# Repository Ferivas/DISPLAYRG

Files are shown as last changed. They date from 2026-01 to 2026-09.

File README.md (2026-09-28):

# Display SAC-A (DISPLAYRG)

Controlador de display LED RG de 8×32 píxeles basado en **ATmega328** (también compatible con ATmega328P), cristal externo de **7.3728 MHz**.

## Estructura del repositorio

| Directorio | Contenido |
|---|---|
| `BASCOM/` | Firmware original en BASCOM-AVR (`DISPLAYSACA_main.bas` + `DISPLAYSACA_archivos.bas`, bootloader XMODEM). Referencia del protocolo y del barrido. |
| `SCH/` | Proyecto Altium Designer (esquemáticos, PCB, salidas generadas). |
| `display/` | Firmware actual en C (PlatformIO + avr-gcc). Maneja el display, serie y LED indicador. |
| `bootloader/` | Bootloader Optiboot para ATmega328 (PlatformIO/Makefile, grabación por USBASP). |

## Firmware `display/`

Puerto a C del firmware BASCOM. Matriz RG multiplexada por registros de desplazamiento de 16 bits (datos `PB0`, reloj `PB1`, todos comparten bus):

- **Columnas** (16 posiciones, cada una cubre 2 columnas físicas 0–15 y 16–31): latch `PD2`, habilitación `PD3`
- **Filas mitad izquierda** (byte rojo + byte verde): latch `PD6`, habilitación `PD7`
- **Filas mitad derecha**: latch `PD4`, habilitación `PD5`
- **LED de señalización**: `PC2` en alto, 100 ms encendido / 900 ms apagado (Timer0 a 100 Hz)

### Temporización

- **Timer2**: barrido de columnas a ~3840 Hz (`TCNT2=226`, prescaler 64) → frame completo de 16 columnas a **240 Hz** (el original BASCOM iba a 960 Hz / 60 Hz y parpadeaba).
- **Timer0**: tick a 100 Hz (`TCNT0=184`, prescaler 1024) para el LED PC2 y el avance de scroll/texto (cada 100 ms).

### Protocolo serie (9600 baud, 8N1)

Trama: **`$` + mensaje + ENTER (`\r`)**. Todo byte fuera de una trama `$`…ENTER se descarta (resincroniza tras ruido). Comandos:

| Comando | Ejemplo | Descripción |
|---|---|---|
| `SETTXT,<texto>,<color>` | `$SETTXT,HOLA,2` | Texto (máx. 48 cars.), color 1=rojo, 2=verde, 3=amarillo |
| `SETCOL,<color>` | `$SETCOL,3` | Cambia color del texto actual |
| `SETSCR,<0\|1>` | `$SETSCR,1` | Scroll on/off (1 columna / 100 ms) |
| `SETTST,<0-4>` | `$SETTST,1` | 0=normal, 1=todo rojo, 2=todo verde, 3=barrido de columna, 4=mitad izq. roja / der. verde |

Respuestas: `OK` o `ERR n`. Comandos sin `$` se ignoran.

### Fuente 5×7

64 caracteres en flash: `0-9`, `A-Z`, **`a-z`**, espacio y punto. Glifo `E` corregido (la última columna era `0x07` en vez de `0x49`).

### Persistencia (EEPROM)

Texto, color y scroll se guardan en EEPROM (magic `0xA5` en addr 0, color en 1, scroll en 2, texto en 3–50) cada vez que llega `SETTXT`/`SETCOL`/`SETSCR`, usando `eeprom_update_*` (solo escribe bytes cambiados). Al arrancar se restauran; si la EEPROM está virgen se usan los valores de inicio ("Bienvenidos a su gimnasio", verde, scroll 1) y se guardan.

### Orientación

El panel está cableado invertido en ambos ejes, así que `display_render()` rota el texto 180°: voltea las filas del glifo (bit r ↔ 6-r) y escribe la columna `31 - pos`. Los modos `SETTST` 3 (barrido) y 4 (mitades) están compensados para mantener su sentido físico.

### Compilar y grabar por USBASP

```bash
cd display
make              # compila entorno atmega328
make upload       # graba ATmega328 por USBASP
make upload328p   # graba ATmega328P por USBASP
pio device monitor   # monitor serie a 9600 baud (recordar el $ delante)
```

Comandos `avrdude` equivalentes (esta tarjeta 328 necesita SCK lento `-B 100`):

```bash
# Comprobar conexión y firma (ATmega328 = 1E 95 14; la P es 1E 95 0F)
avrdude -p atmega328 -c usbasp -B 100

# Grabar firmware y verificar (imprescindible: sin verificación no hay SUCCESS válido)
avrdude -p atmega328 -c usbasp -B 100 -U flash:w:.pio/build/atmega328/firmware.hex:i
avrdude -p atmega328 -c usbasp -B 100 -U flash:v:.pio/build/atmega328/firmware.hex:i

# Fusibles sin bootloader (arranque en 0x0000, cristal externo, SPIEN)
avrdude -p atmega328 -c usbasp -B 100 -U hfuse:w:0xD9:m -U lfuse:w:0xF7:m -U efuse:w:0xFD:m
```

Notas de grabación:
- Un `verification error` indica escritura corrupta (reintentar / revisar conexión USBASP).
- Con `HFUSE=0xDE` (bootloader) el micro arranca en la sección de boot y el programa nunca corre.
- La grabación por USBASP hace chip-erase y **borra la EEPROM**: al primer arranque se restauran los valores de inicio ("Bienvenidos a su gimnasio", verde, scroll 1).

## Bootloader (`bootloader/`)

Optiboot compilado con el toolchain AVR de PlatformIO (LED en PC2, 3 parpadeos al arrancar, protocolo STK500v1 a **38400 baud**):

```bash
cd bootloader
make                    # bootloader ATmega328 (498 bytes)
make TARGET=atmega328p  # variante ATmega328P
make upload / make upload328p   # graba bootloader + fusibles por USBASP
```

Salida: `bootloader/build/optiboot_atmega328.hex` (ignorado por git).

Fusibles con bootloader: `HFUSE=0xDE` (BOOTRST, sección de 512 B), `LFUSE=0xF7`, `EFUSE=0xFD`.

### Grabar la aplicación por serie (con bootloader instalado)

Una vez grabado Optiboot, el firmware de `display/` se puede actualizar por el puerto serie sin USBASP (el bootloader se activa al resetear; hay ~1 s para iniciar la subida):

```bash
cd display
pio run   # o make, genera .pio/build/atmega328/firmware.hex

avrdude -p atmega328 -c arduino -b 38400 -P /dev/ttyUSB0 \
  -U flash:w:.pio/build/atmega328/firmware.hex:i
```

Notas:
- Ajustar `-P` al puerto real (`/dev/ttyUSB0`, `COM3`, …).
- La subida por bootloader **no borra la EEPROM**: se conservan el último texto, color y scroll guardados.
- Si el micro no responde, pulsar reset justo antes del comando (o usar USBASP para regrabar bootloader + fusibles).

## Historial de cambios

- Puerto del firmware BASCOM a C (`display/`, PlatformIO + avr-gcc).
- Barrido Timer2 a 240 Hz de frame (el original a 60 Hz parpadeaba); Timer0 a 100 Hz (LED PC2 + scroll).
- Protocolo serie enmarcado `$`…ENTER con `SETTXT`/`SETCOL`/`SETSCR`/`SETTST`.
- Fuente 5×7 de 64 caracteres (glifo `E` corregido, minúsculas `a-z` añadidas).
- Rotación de texto 180° (panel cableado invertido en ambos ejes); tests 3/4 compensados.
- Persistencia de texto/color/scroll en EEPROM (`config_load`/`config_save`).
- Texto de inicio: "Bienvenidos a su gimnasio", verde, scroll activado.
- Bootloader Optiboot a 38400 baud con LED en PC2.

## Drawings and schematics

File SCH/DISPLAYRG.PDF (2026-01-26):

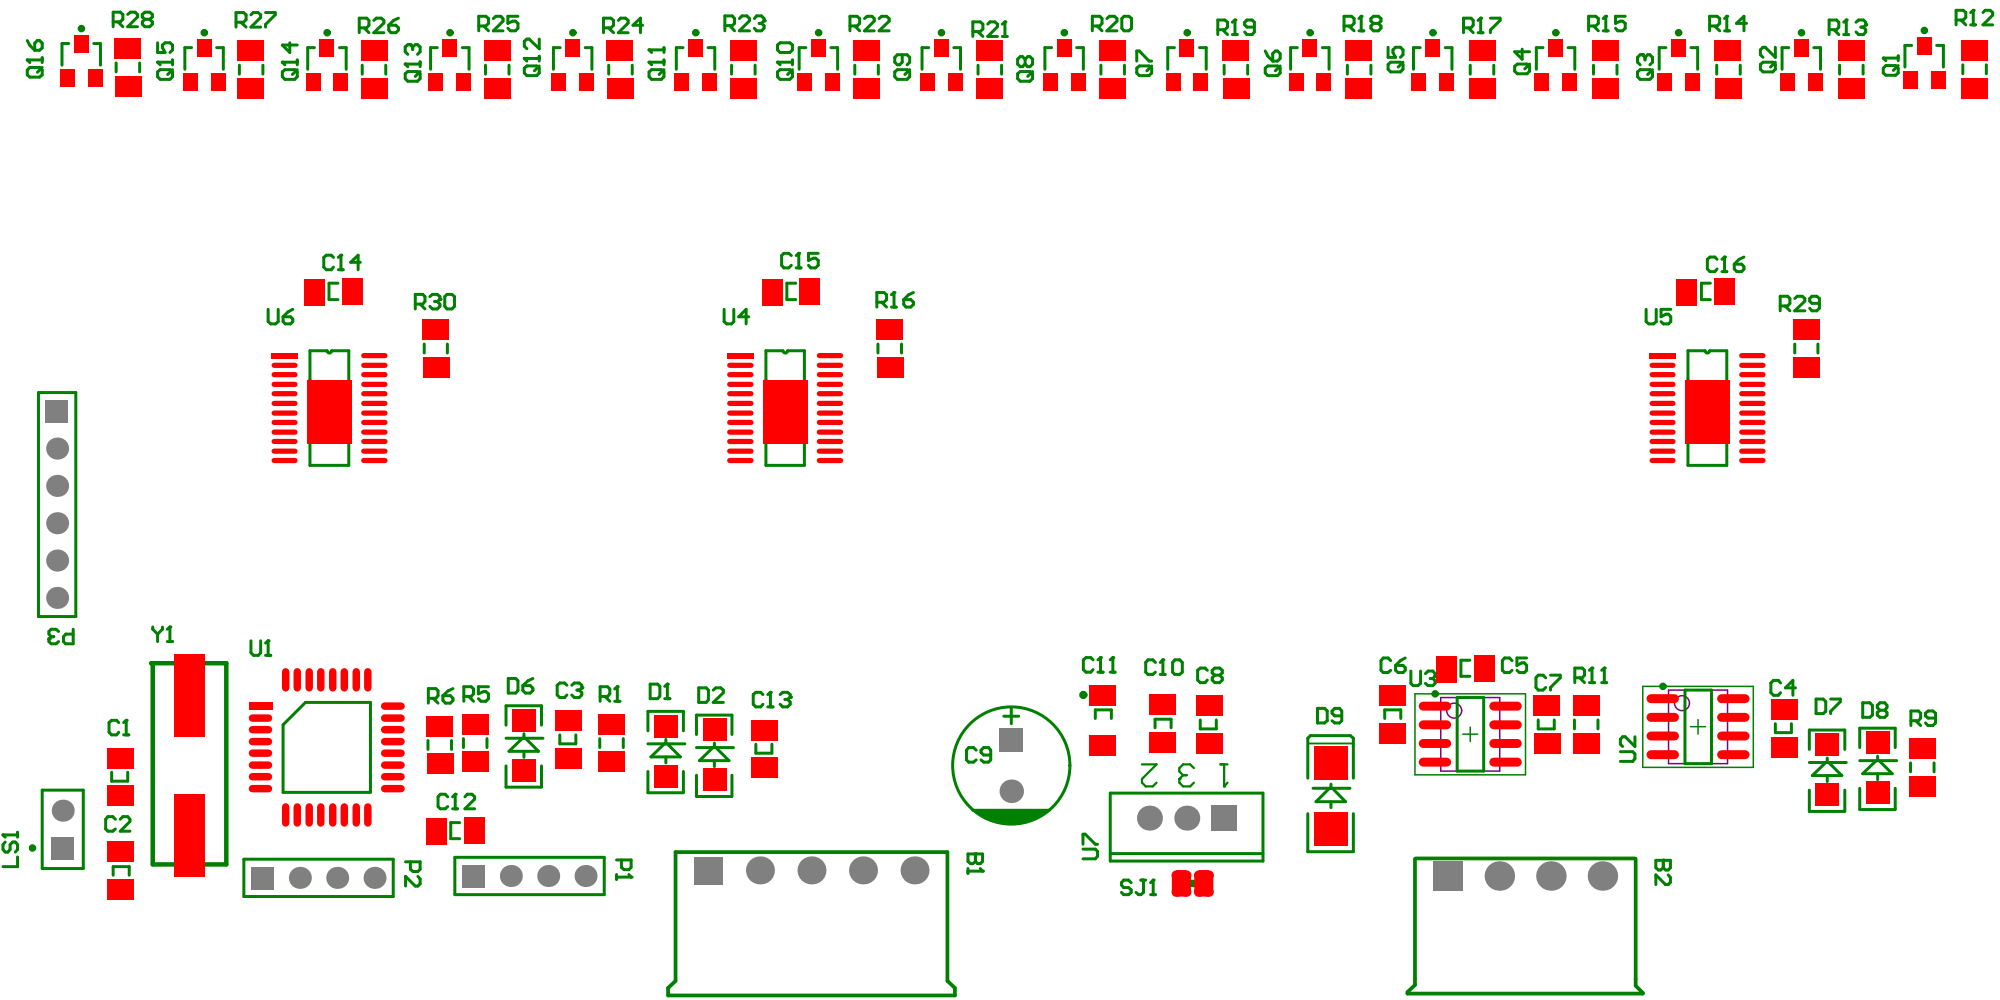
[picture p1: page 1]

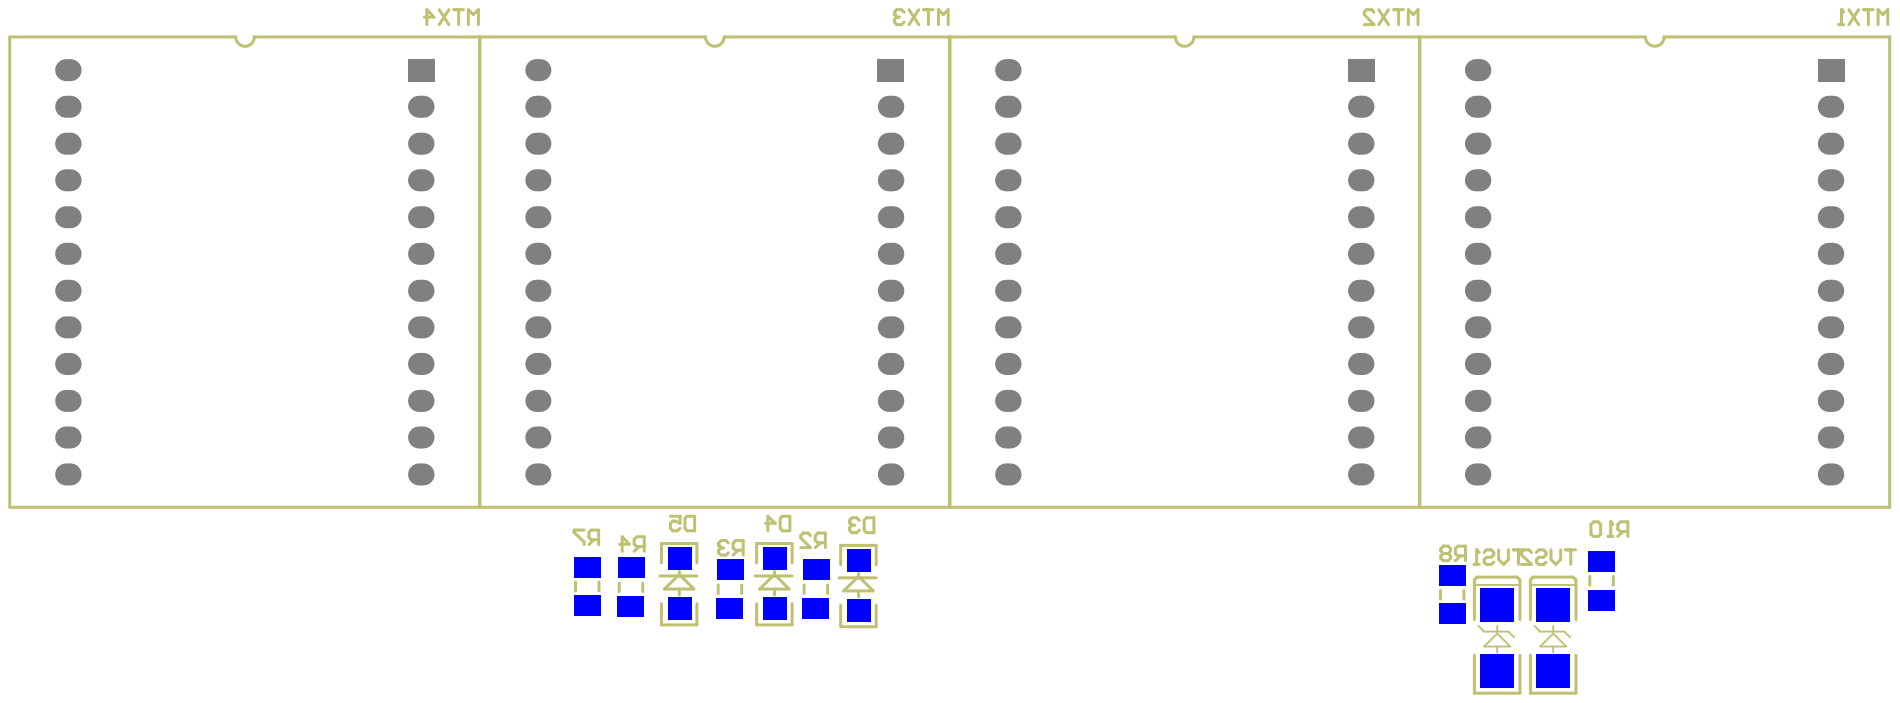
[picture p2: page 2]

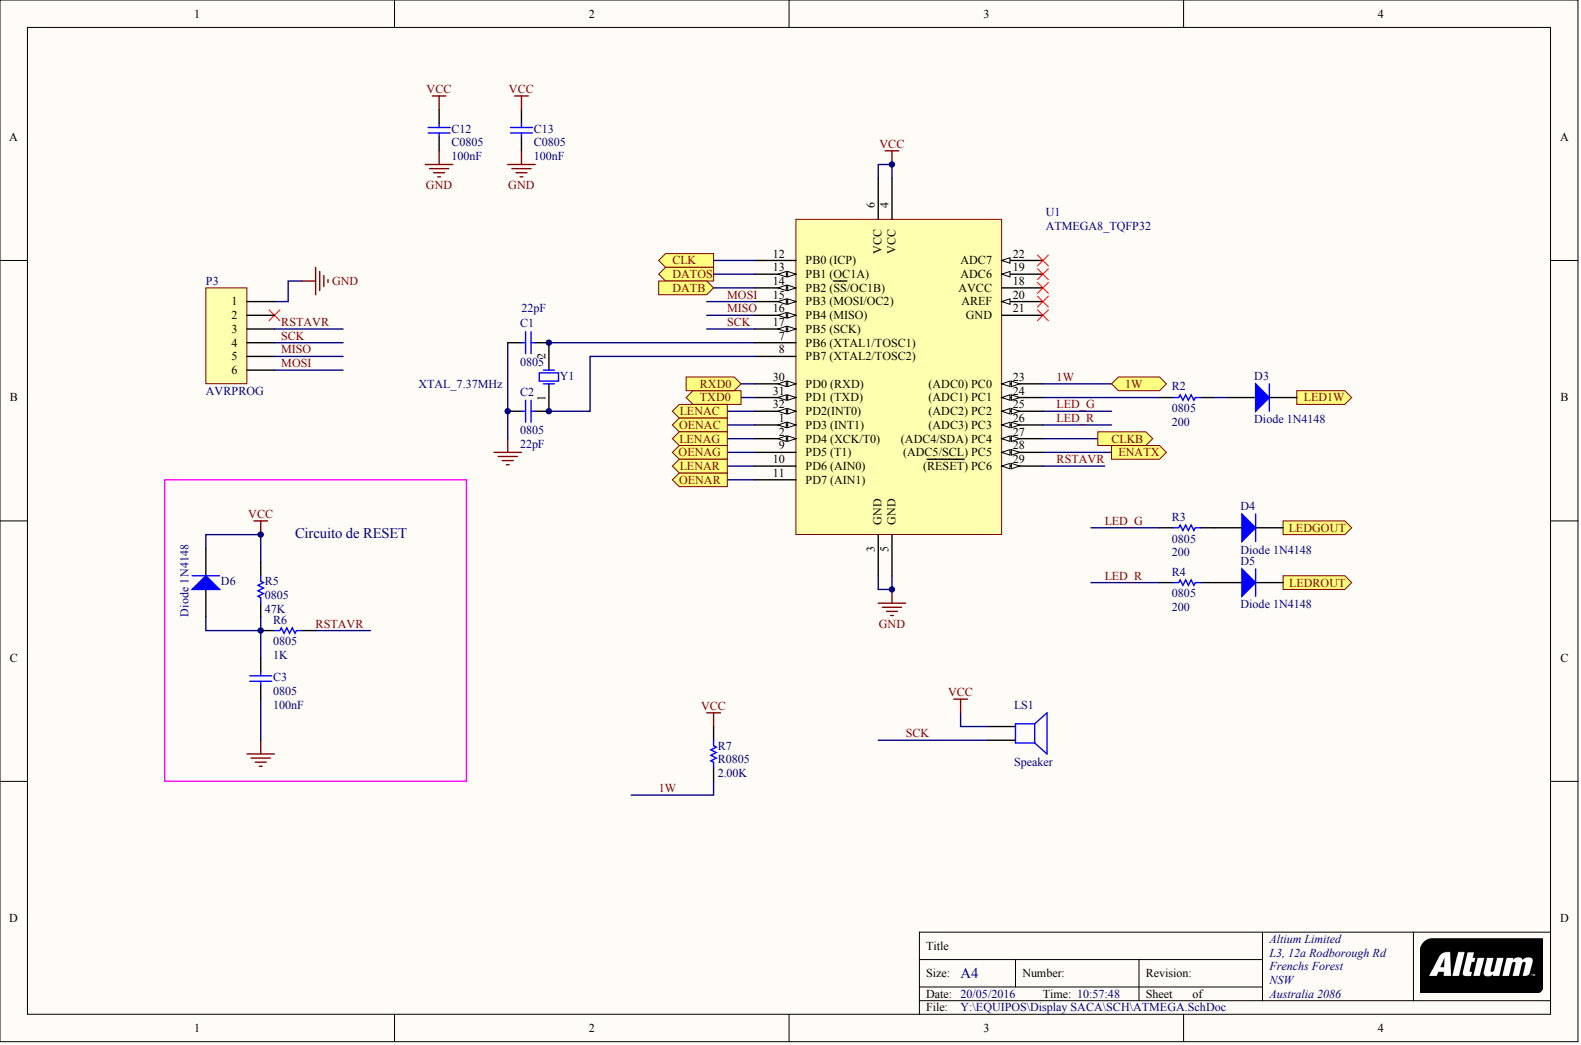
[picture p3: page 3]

Title | Altium Limited L3, 12a Rodborough Rd Frenchs Forest NSW Australia 2086

A Size: | Number: | Revision:

Date: File: 20/05/2016 Time: 10:57:48 | | Sheet of

POS\Display SACA\SCH\ATMEGA.SchDoc

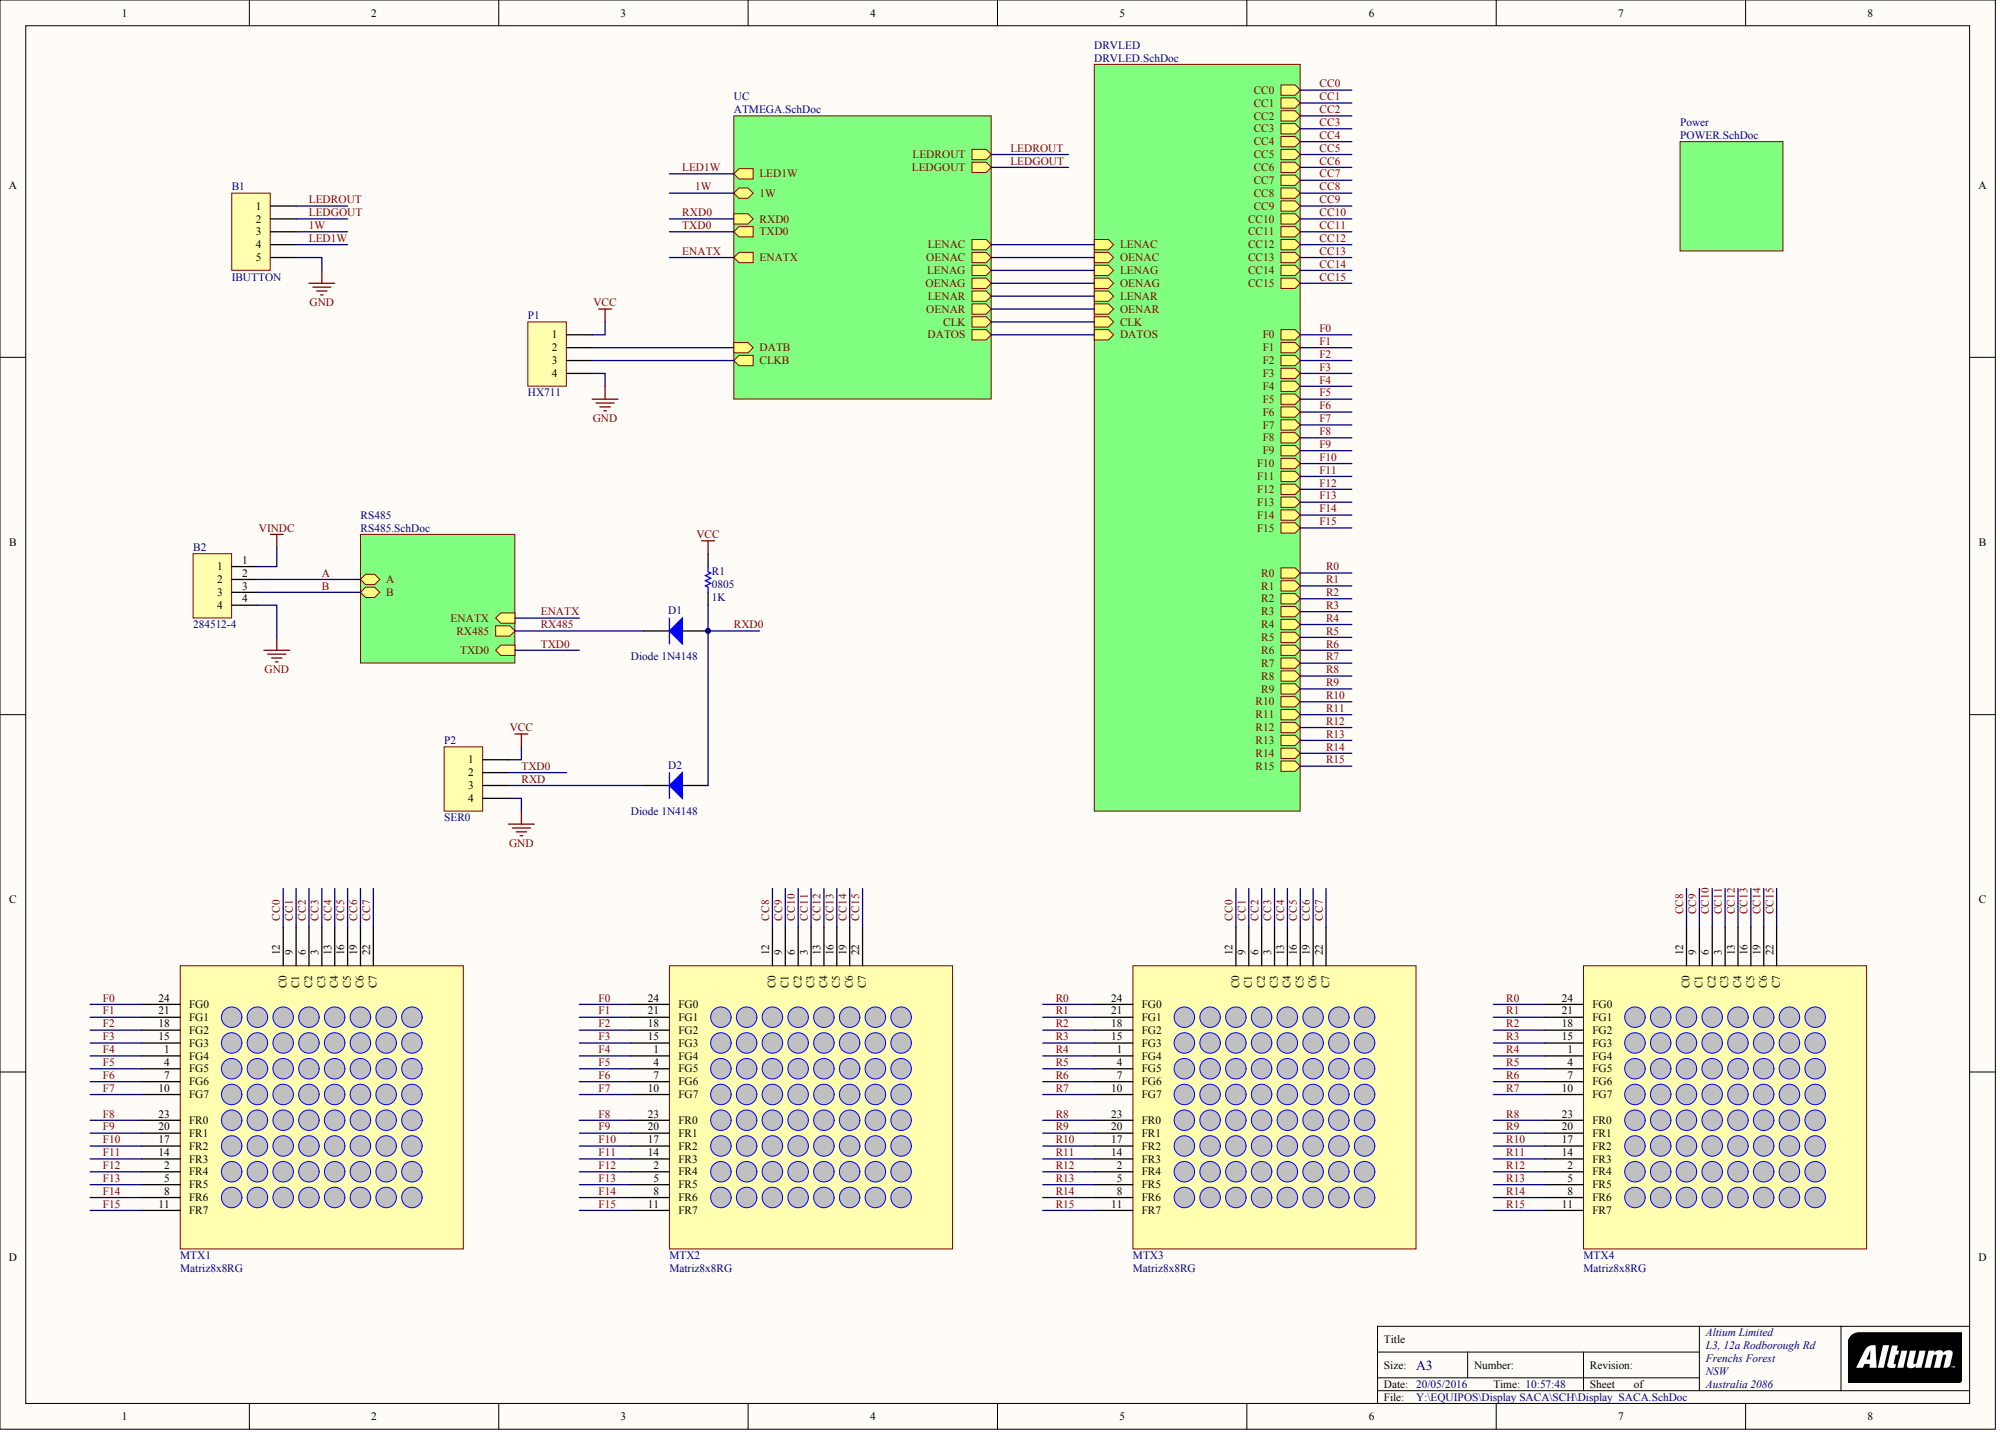
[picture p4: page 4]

Title | Altium Limited L3, 12a Rodborough Rd Australia 2086

Date: File: 20/05/2016 10:57:48

POS\Display SACA\SCH\Display_SACA.SchDoc

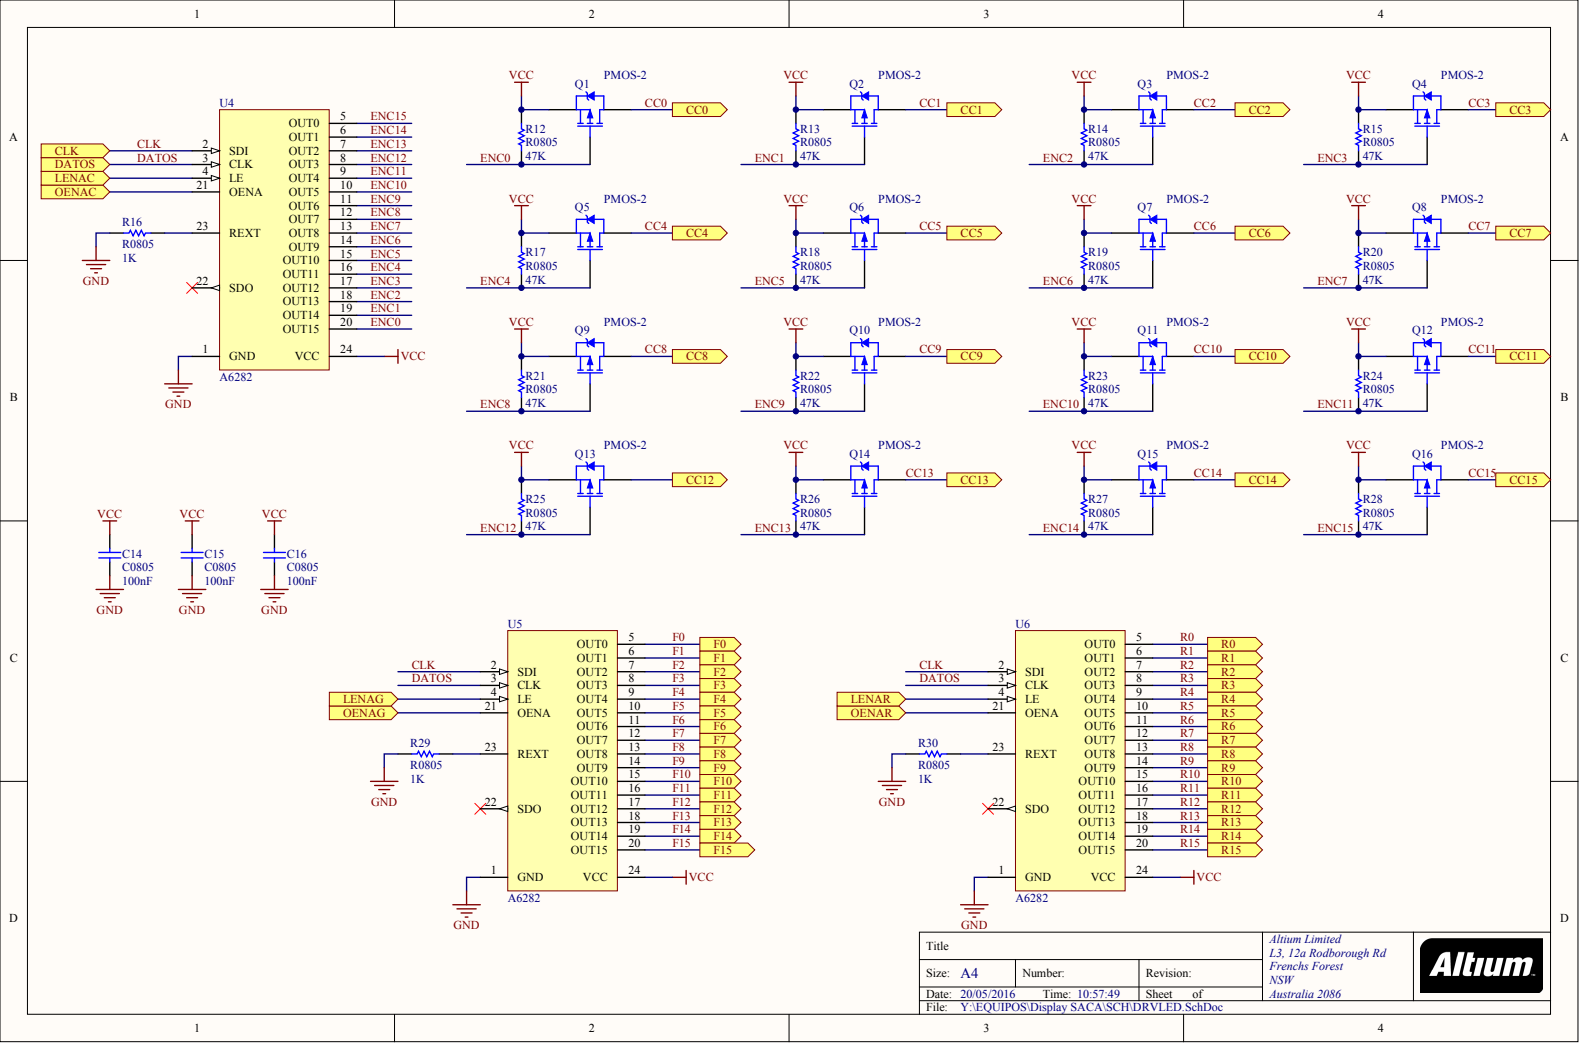
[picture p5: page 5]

Title | Altium Limited L3, 12a Rodborough Rd Australia 2086

Date: 20/05/2016 10:57:49

Y:\EQUIPOS\Display SACA\SCH\DRVLED.SchDoc

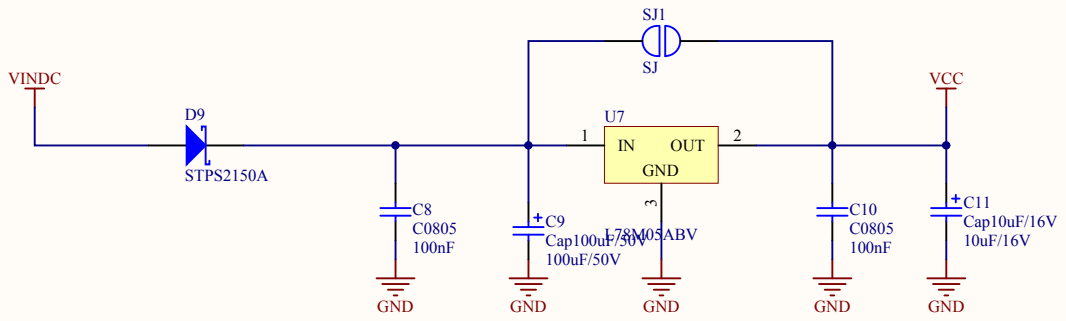
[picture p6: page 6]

Title * | WATCHING Joaquin Pinto E4-358 y Amazonas Quito-Ecuador www.watching.com.ec | Cannot open file Place logo here Z:\EQUIPOS\SCH_li

20/05/2016 10:57:49 | | * *
DcumentFullPathAndName

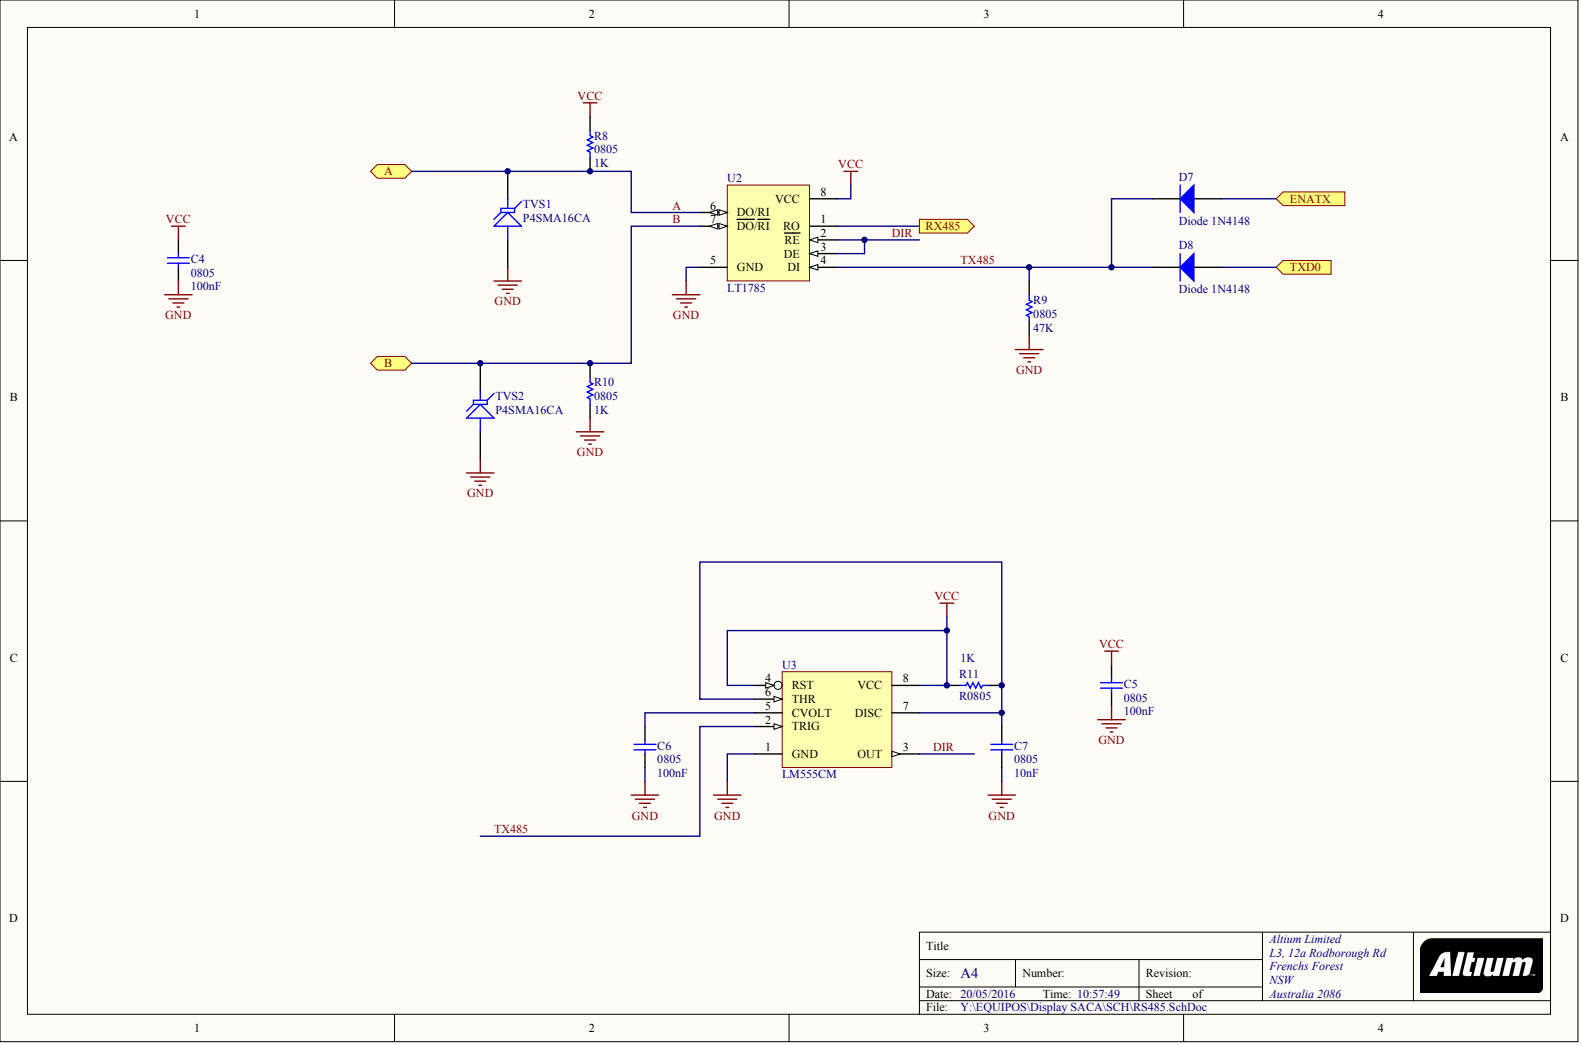
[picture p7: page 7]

Title | Altium Limited L3, 12a Rodborough Rd Australia 2086

Y:\EQUIPOS\Display SACA\SCH\RS485.SchDoc

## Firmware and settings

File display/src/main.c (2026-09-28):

#include <avr/io.h>
#include <avr/interrupt.h>
#include <string.h>
#include <stdlib.h>
#include "display.h"

#define UART_RX_SIZE 64
#define F_CPU 7372800UL
#define START_CHAR '$'

static volatile uint8_t uart_rx_buffer[UART_RX_SIZE];
static volatile uint8_t uart_rx_head;
static volatile uint8_t uart_rx_collect;

ISR(TIMER0_OVF_vect) {
    TCNT0 = 184;
    timer0_tick++;
    if (timer0_tick >= 100) timer0_tick = 0;

    if (timer0_tick < 10) {
        PORTC |= (1 << LED_PIN);
    } else {
        PORTC &= ~(1 << LED_PIN);
    }

    newseg_tick++;
    if (newseg_tick >= 10) {
        newseg_tick = 0;
        newseg_flag = 1;
    }
}

ISR(TIMER2_OVF_vect) {
    TCNT2 = 226;
    display_col_scan();
}

ISR(USART_RX_vect) {
    uint8_t c = UDR0;

    if (c == START_CHAR) {
        uart_rx_head = 0;
        uart_rx_collect = 1;
        return;
    }

    if (!uart_rx_collect) {
        return;
    }

    if (c == '\r' || c == '\n') {
        if (uart_rx_collect == 1) {
            uart_rx_collect = 2;
        } else if (uart_rx_collect == 3) {
            uart_rx_collect = 0;
        }
        return;
    }

    if (uart_rx_head < UART_RX_SIZE - 1) {
        uart_rx_buffer[uart_rx_head++] = c;
    } else {
        uart_rx_collect = 3;
    }
}

static void uart_putc(char c) {
    while (!(UCSR0A & _BV(UDRE0)));
    UDR0 = c;
}

static void uart_puts(const char *s) {
    while (*s) {
        uart_putc(*s++);
    }
}

static void parse_and_execute(const char *cmd) {
    char cmd_name[7];
    uint8_t i;

    for (i = 0; i < 6 && cmd[i] != ',' && cmd[i] != '\0'; i++) {
        cmd_name[i] = cmd[i];
    }
    cmd_name[i] = '\0';

    for (uint8_t j = 0; j < i; j++) {
        if (cmd_name[j] >= 'a' && cmd_name[j] <= 'z') {
            cmd_name[j] -= 32;
        }
    }

    if (strcmp_P(cmd_name, PSTR("SETTXT")) == 0) {
        const char *text_start = strchr(cmd, ',');
        if (!text_start) { uart_puts("ERR 2\r\n"); return; }
        text_start++;
        const char *color_str = strchr(text_start, ',');
        if (!color_str) { uart_puts("ERR 2\r\n"); return; }
        char text_buf[49];
        uint8_t text_len = color_str - text_start;
        if (text_len > 48) text_len = 48;
        memcpy(text_buf, text_start, text_len);
        text_buf[text_len] = '\0';
        uint8_t color_val = atoi(color_str + 1);
        if (color_val < 1 || color_val > 3) { uart_puts("ERR 6\r\n"); return; }
        display_set_test(0);
        display_set_text(text_buf, color_val);
        uart_puts("OK\r\n");
    } else if (strcmp_P(cmd_name, PSTR("SETCOL")) == 0) {
        const char *color_str = strchr(cmd, ',');
        if (!color_str) { uart_puts("ERR 2\r\n"); return; }
        uint8_t color_val = atoi(color_str + 1);
        if (color_val < 1 || color_val > 3) { uart_puts("ERR 6\r\n"); return; }
        display_set_color(color_val);
        uart_puts("OK\r\n");
    } else if (strcmp_P(cmd_name, PSTR("SETSCR")) == 0) {
        const char *scroll_str = strchr(cmd, ',');
        if (!scroll_str) { uart_puts("ERR 2\r\n"); return; }
        uint8_t scroll_val = atoi(scroll_str + 1);
        display_set_scroll(scroll_val ? 1 : 0);
        uart_puts("OK\r\n");
    } else if (strcmp_P(cmd_name, PSTR("SETTST")) == 0) {
        const char *tst_str = strchr(cmd, ',');
        if (!tst_str) { uart_puts("ERR 2\r\n"); return; }
        uint8_t tst_val = atoi(tst_str + 1);
        display_set_test(tst_val);
        uart_puts("OK\r\n");
    } else {
        uart_puts("ERR 1\r\n");
    }
}

void display_serial_cmd(void) {
    char buf[UART_RX_SIZE];
    uint8_t i, n;

    if (uart_rx_collect != 2) {
        return;
    }

    cli();
    n = uart_rx_head;
    for (i = 0; i < n && i < sizeof(buf) - 1; i++) {
        buf[i] = uart_rx_buffer[i];
    }
    uart_rx_collect = 0;
    sei();

    buf[i] = '\0';
    if (i > 0) {
        parse_and_execute(buf);
    }
}

int main(void) {
    display_init();

    UCSR0B = (1 << RXEN0) | (1 << TXEN0) | (1 << RXCIE0);
    UCSR0C = (1 << UCSZ01) | (1 << UCSZ00);
    UBRR0H = (uint8_t)(F_CPU / 16 / 9600 - 1) >> 8;
    UBRR0L = (uint8_t)(F_CPU / 16 / 9600 - 1);

    TCNT0 = 184;
    TIMSK0 |= (1 << TOIE0);
    TCCR0B |= (1 << CS02) | (1 << CS00);

    TCNT2 = 226;
    TIMSK2 |= (1 << TOIE2);
    TCCR2B |= (1 << CS22) | (1 << CS21);

    sei();

    config_load();

    while (1) {
        display_serial_cmd();
        if (test_mode == 3 && newseg_flag) {
            newseg_flag = 0;
            test_col = (test_col + 1) % 16;
        }
        if (test_mode != 0) continue;
        if (scroll_enabled && newseg_flag) {
            newseg_flag = 0;
            display_scroll_text();
        }
    }

    return 0;
}

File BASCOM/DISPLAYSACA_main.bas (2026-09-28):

'Main.bas
'
'                 WATCHING Soluciones Tecnológicas
'                    Fernando Vásquez - 25.06.15
'
' Programa para almacenar los datos que se reciben por el puerto serial a una
' memoria SD
'


$version 0 , 1 , 137
$regfile = "m328pdef.dat"
$crystal = 7372800
$baud = 9600


$hwstack = 80
$swstack = 80
$framesize = 80


'Declaracion de constantes



'Configuracion de entradas/salidas
Led1 Alias Portc.2                                          'LED ROJO
Config Led1 = Output

Pinbug Alias Portb.3
Config Pinbug = Output


Datos Alias Portb.0
Config Datos = Output

Sck Alias Portb.1
Config Sck = Output

Lenac Alias Portd.2
Config Lenac = Output

Oenac Alias Portd.3
Config Oenac = Output

Lenag Alias Portd.4
Config Lenag = Output

Oenag Alias Portd.5
Config Oenag = Output

Lenar Alias Portd.6
Config Lenar = Output

Oenar Alias Portd.7
Config Oenar = Output

'Configuración de Interrupciones
'TIMER0
Config Timer0 = Timer , Prescale = 1024                     'Ints a 100Hz si Timer0=184
On Timer0 Int_timer0
Enable Timer0
Start Timer0

'TIMER0
Config Timer2 = Timer , Prescale = 64
On Timer2 Int_timer2
Enable Timer2
Start Timer2

' Puerto serial 1
Open "com1:" For Binary As #1
On Urxc At_ser1
Enable Urxc


Enable Interrupts


'*******************************************************************************
'* Archivos incluidos
'*******************************************************************************
$include "DISPLAYSACA_archivos.bas"



'Programa principal

Call Inivar()


Do

   If Sernew = 1 Then                                       'DATOS SERIAL 1
      Reset Sernew
      Print #1 , "SER1=" ; Serproc
      Call Procser()
   End If

   If Inileer = 1 Then
      Reset Inileer

      For Tmpb = 1 To 32
         Print #1 , "BUF_R(" ; Tmpb ; ")=" ; Hexval(bufframr(tmpb)) ; " ; ";
         Print #1 , "BUF_G(" ; Tmpb ; ")=" ; Hexval(bufframg(tmpb))
      Next

   End If

   If Inival = 1 Then
      Reset Inival
      Call Displayval()
   End If

   If Inipeso = 1 Then
      Reset Inipeso
      Set Peso
      Call Displayval()
      Wait 1
      Call Dispunidad()
      Wait 1
      Call Displayval()
      Wait 1
      Call Dispunidad()
      Wait 1
      If Unidad = 1 Then
         Reset Peso
         Unidad = 7
         Call Dispunidad()
         Wait 2
      End If

   End If

   If Initest = 1 Then
      Print #1 , "INI TEST"

      For K = 1 To 32
         Bufframr(k) = 0
         Bufframg(k) = 0
      Next

      Do
         If Sernew = 1 Then                                 'DATOS SERIAL 1
            Reset Sernew
            Print #1 , "SER1=" ; Serproc
            Call Procser()
         End If

         If Newseg = 1 Then
            Reset Newseg
            Incr K
            Print #1 , "Newseg," ; K

            For J = 1 To 32

               If Color = 1 Then
                  Bufframg(j) = &H00
               Else
                  Bufframr(j) = &H00
               End If

            Next

            For J = 1 To 32

               If J = K Then

                  If Color = 1 Then
                     Bufframg(j) = &HFF
                  Else
                     Bufframr(j) = &HFF
                  End If

               End If
            Next

            If K > 32 Then
               Tmpb = K Mod 8
               Print #1 , Tmpb

               For J = 1 To 32

                  If Color = 1 Then
                     Bufframg(j).tmpb = 1
                  Else
                     Bufframr(j).tmpb = 1
                  End If

               Next

            End If

            K = K Mod 48
         End If

      Loop Until Initest = 0

   End If

   If Newseg = 1 And Peso = 0 Then
      Reset Newseg
      Incr Cntrani
      If Esperar = 1 Then

         Select Case Cntrani
            Case 1:
               Unidad = 9
               Incr Color
               Color = Color Mod 2
               Call Dispunidad()
            Case 6:
               For K = 1 To 32
                  Bufframr(k) = 0
                  Bufframg(k) = 0
               Next
         End Select

      Else

         Select Case Cntrani
            Case 1:
               Unidad = 2
               Color = 1
               Call Dispunidad()

            Case 4:
               Unidad = 3
               Color = 0
               Call Dispunidad()

            Case 6:
               For K = 1 To 32
                  Bufframr(k) = 0
                  Bufframg(k) = 0
               Next


         End Select

      End If

      Cntrani = Cntrani Mod 12
   End If

   If Findelay = 1 Then
      Reset Findelay
      Reset Esperar
      Unidad = 8
      Color = 0
      Call Dispunidad()
   End If

Loop

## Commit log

2026-01-26 Esquemáticos en Protel y programas en Bascom
    [ATMEGA.SchDoc, DRVLED.SchDoc, Display_SACA.PcbDoc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]
2026-09-26 Display SAC-A: firmware display/ en C, bootloader Optiboot y docs
    - display/: driver 8x32 RG en C (PlatformIO/avr-gcc) portado del
    firmware BASCOM. Barrido Timer2 a 240 Hz de frame, Timer0 100 Hz,
    LED PC2, protocolo serie enmarcado $...ENTER (SETTXT/SETCOL/
    SETSCR/SETTST), fuente 5x7 de 64 cars. (E corregida, a-z),
    colores rojo/verde/amarillo, render atomico sin tearing
    - bootloader/: proyecto Optiboot para ATmega328/328P (make, USBASP)
    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
2026-09-27 Create DRV_A6282.PDF
    driver led
2026-09-28 Depuracion archivos
    [ATMEGA.SchDoc, DRVLED.SchDoc, Display_SACA.PcbDoc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]
2026-09-28 display: rotar texto 180 grados (panel cableado invertido)
    - display_render(): flip vertical de glifos (r<->6-r) + columna 31-pos
    - SETTST 3/4 compensados para mantener sentido fisico
    - README/AGENTS: nota de orientacion
    [display.c]
2026-09-28 display: persistir texto/color/scroll en EEPROM
    - config_save() en SETTXT/SETCOL/SETSCR con eeprom_update_*
    (magic 0xA5, solo escribe bytes cambiados)
    - config_load() al arrancar; EEPROM virgen -> valores de inicio
    (Bienvenidos a su gimnasio, verde, scroll 1)
    - README/AGENTS: seccion de persistencia
2026-09-28 README: comandos USBASP y serie (bootloader) + historial de cambios
    - Comandos avrdude explicitos: firma, flash w/v, fusibles sin
    bootloader; nota de chip-erase (borra EEPROM)
    - Subida de la aplicacion por serie con Optiboot (-c arduino,
    38400 baud, reset previo); la EEPROM se conserva
    - Historial de cambios del proyecto
